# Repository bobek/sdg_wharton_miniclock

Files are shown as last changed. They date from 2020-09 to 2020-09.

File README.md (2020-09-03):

# SDK Electronics Mini Clock

[Wharton Studio Clocks](https://www.wharton.co.uk/digital-clocks/4900050-radio-tv-studio-digital-clocks.htm) are pretty iconic. You can meet their iconic design in many TV and Radio studios around the world (I first met them, when being at CERN). They are a bit pricey.

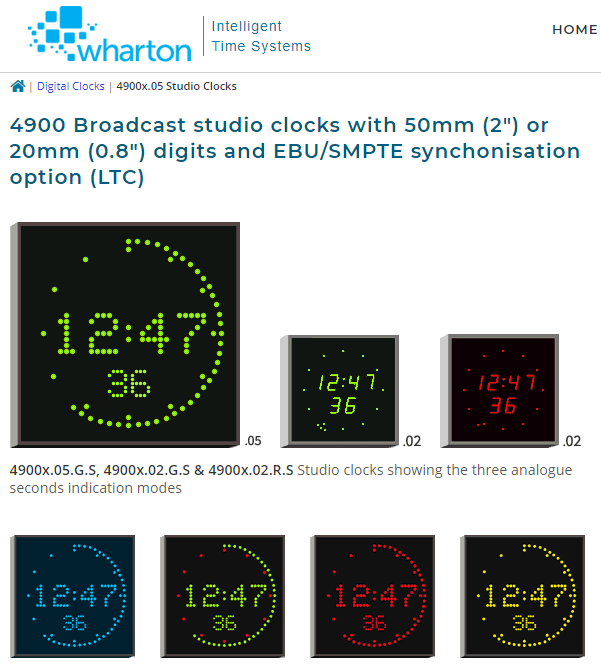
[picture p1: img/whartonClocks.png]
Wharton Studio clocks


Fortunately, Steven from SDG Electronics have designed [mini clock](https://sdgelectronics.co.uk/wharton/) inspired by Wharton's look. Check the project page for an excellent videos describing the whole design as well as walk-through how to upload production files to JLCPCB for manufacturing.

Purpose of this repository is to provide mirror for the production files as well as to have a place to keep history of changes into the firmware. And maybe also to collaborate. PR are welcome.

Project structure:
- [`fw`](fw/): Code for ESP32-WROOM-32D using Espressif IDF.
- [`hw`](hw/): Hardware design files.
- [`hw_prodfiles`](hw_prodfiles/): Hardware production files. Tested with JLCPCB. Layer stack is `GTL--G2L--G3L--GBL`.

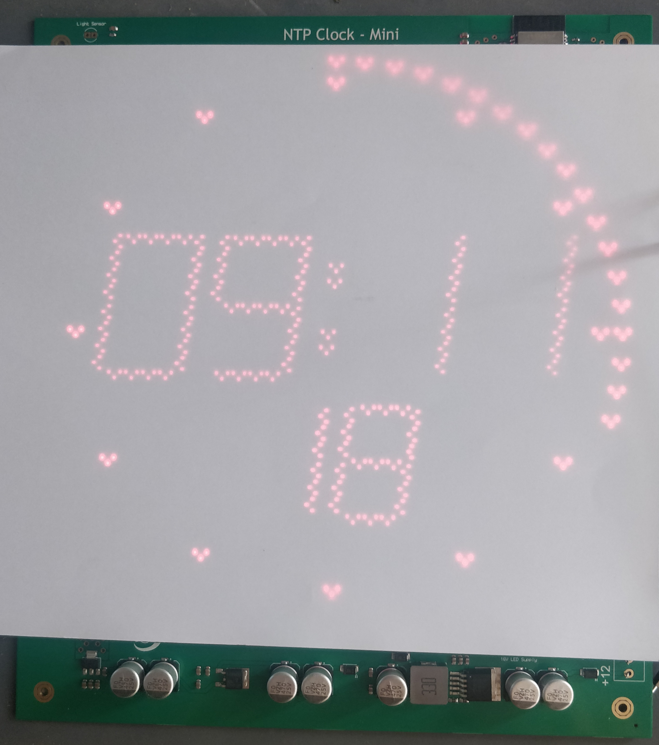
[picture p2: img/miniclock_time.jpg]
Mini Clock showing time

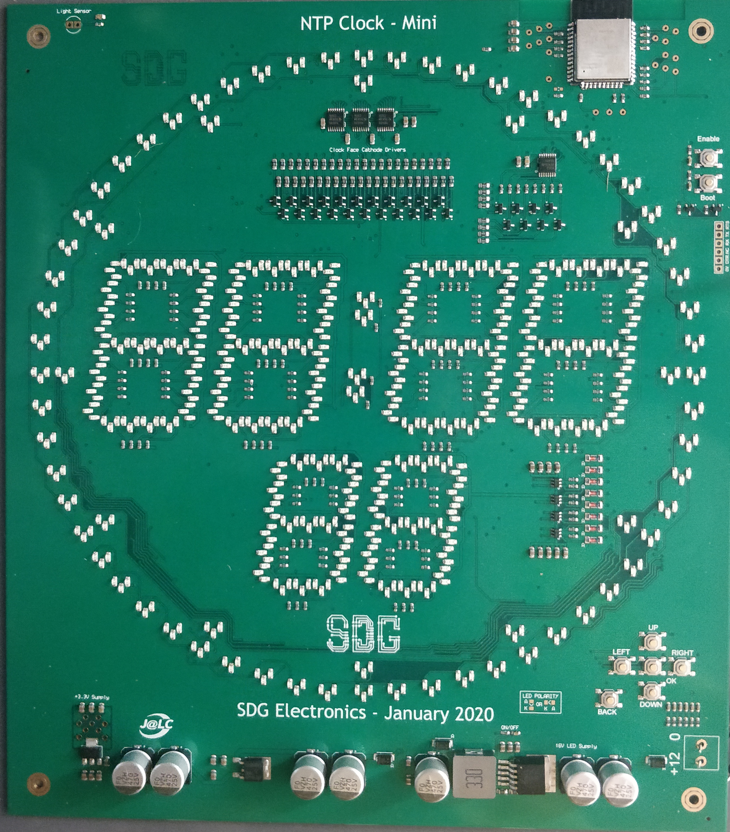
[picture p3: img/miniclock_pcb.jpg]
Mini Clock PCB


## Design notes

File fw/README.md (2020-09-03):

# Mini Clock Firmware

Firmware uses Espressif ESP-IDF. I've initially tried to get it working with PlatformIO, but was not successful as there are compatibility issues between cmake based IDF vs PlatformIO. Thus project is using IDF directly. I am on Linux (Debian), so the following steps are tested only there.

- Install IDF to your computer as described at [Espressif documentation](https://docs.espressif.com/projects/esp-idf/en/latest/esp32/get-started/index.html).
- [Configure your environment](https://docs.espressif.com/projects/esp-idf/en/latest/esp32/get-started/index.html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). For example by `source ~/esp/esp-idf/export.sh`.
- Configure project with `idf.py menuconfig`. There is also a configuration section `Small Clock Configuration`.
- Build with `idf.py build` and flash with `idf.py flash`.

## Configuring local timezone

There is a `LOCAL_TZ_DATA` configuration option. It expects tzdata timezone configuration string. If on Linux, you can use the simple python script `get_tz_data.py` to get it from your local tzdata definition (typically located at `/usr/share/zoneinfo/`). For example:

```
$ ./get_tz_data.py Europe/Prague
CET-1CEST,M3.5.0,M10.5.0/3
$ ./get_tz_data.py America/New_York       
EST5EDT,M3.2.0,M11.1.0
```

You can get list of possible timezone names with `timedatectl list-timezones` or just simply check which files are in the zoneinfo directory.

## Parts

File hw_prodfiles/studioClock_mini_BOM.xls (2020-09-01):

Comment | Designator | Footprint | LCSC Part #
2.2uF | C4 C5 C18 C19 C72 | 0805 | C15850
10uF | C6-9 C20 C21 C25-30 C32 C34 C36 C38 C75 C76 C78 C79 C81-87 | 0805 | C15850
100nF | C10-17 C80 | 0603 | C14663
470uF 25V | C23 C24 C68 C70 C73 C74 C77 | ELECT-10X10 | C266042
100nF | C31 C33 C35 C37 C67 | 0805 | C49678
SS54 | D2 D171 D172 | DO-214AC | C22452
LED | D3-170 D183-500 D501-704 | 0805LED | C72037
33uH | L2 | 12.5X2.5 IND | C149576
S8050 | Q1-2 Q7-36 | SOT23-3 | C2146
WST2011 | Q3-6 | SOT23-6 | C148368
10k | R1-3 R8-14 R446-447 | 0603 | C25804
1R | R4-7 R71-74 R429-430 R432 R433 R435 R436 R438 R444 R445 | 0603 | C22936
10R | R15-70 R75-176 | 0603 | C22859
1k | R177-183 R236 R451 | 0603 | C21190
2k | R184-191 | 0603 | C22975
1k | R192-199 R208-215 R224-229 | 0805 | C17513
51R | R200-207 R216-223 R230-235 | 0805 | C17738
2k | R452 | 0805 | C17604
22k | R453 | 0805 | C17560
470R | R454-461 | 0805 | C17710
AMS1117-3.3 | RG2 | SOT223-3 | C6186
XL6019 | RG3 | TO-263-5E | C73018
TACTILE5X5 | SW1-8 | TS-1187A | C318889
L7805 | U1 | TO252 | C310413
SN74AHC595PWR | U6-9 | TSSOP16 | C271269
ZMM5V6 | ZD1-8 | MINIMELF | C8062

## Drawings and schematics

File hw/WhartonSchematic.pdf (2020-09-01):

A | B | C | D | E | F | G | H | J | K

0

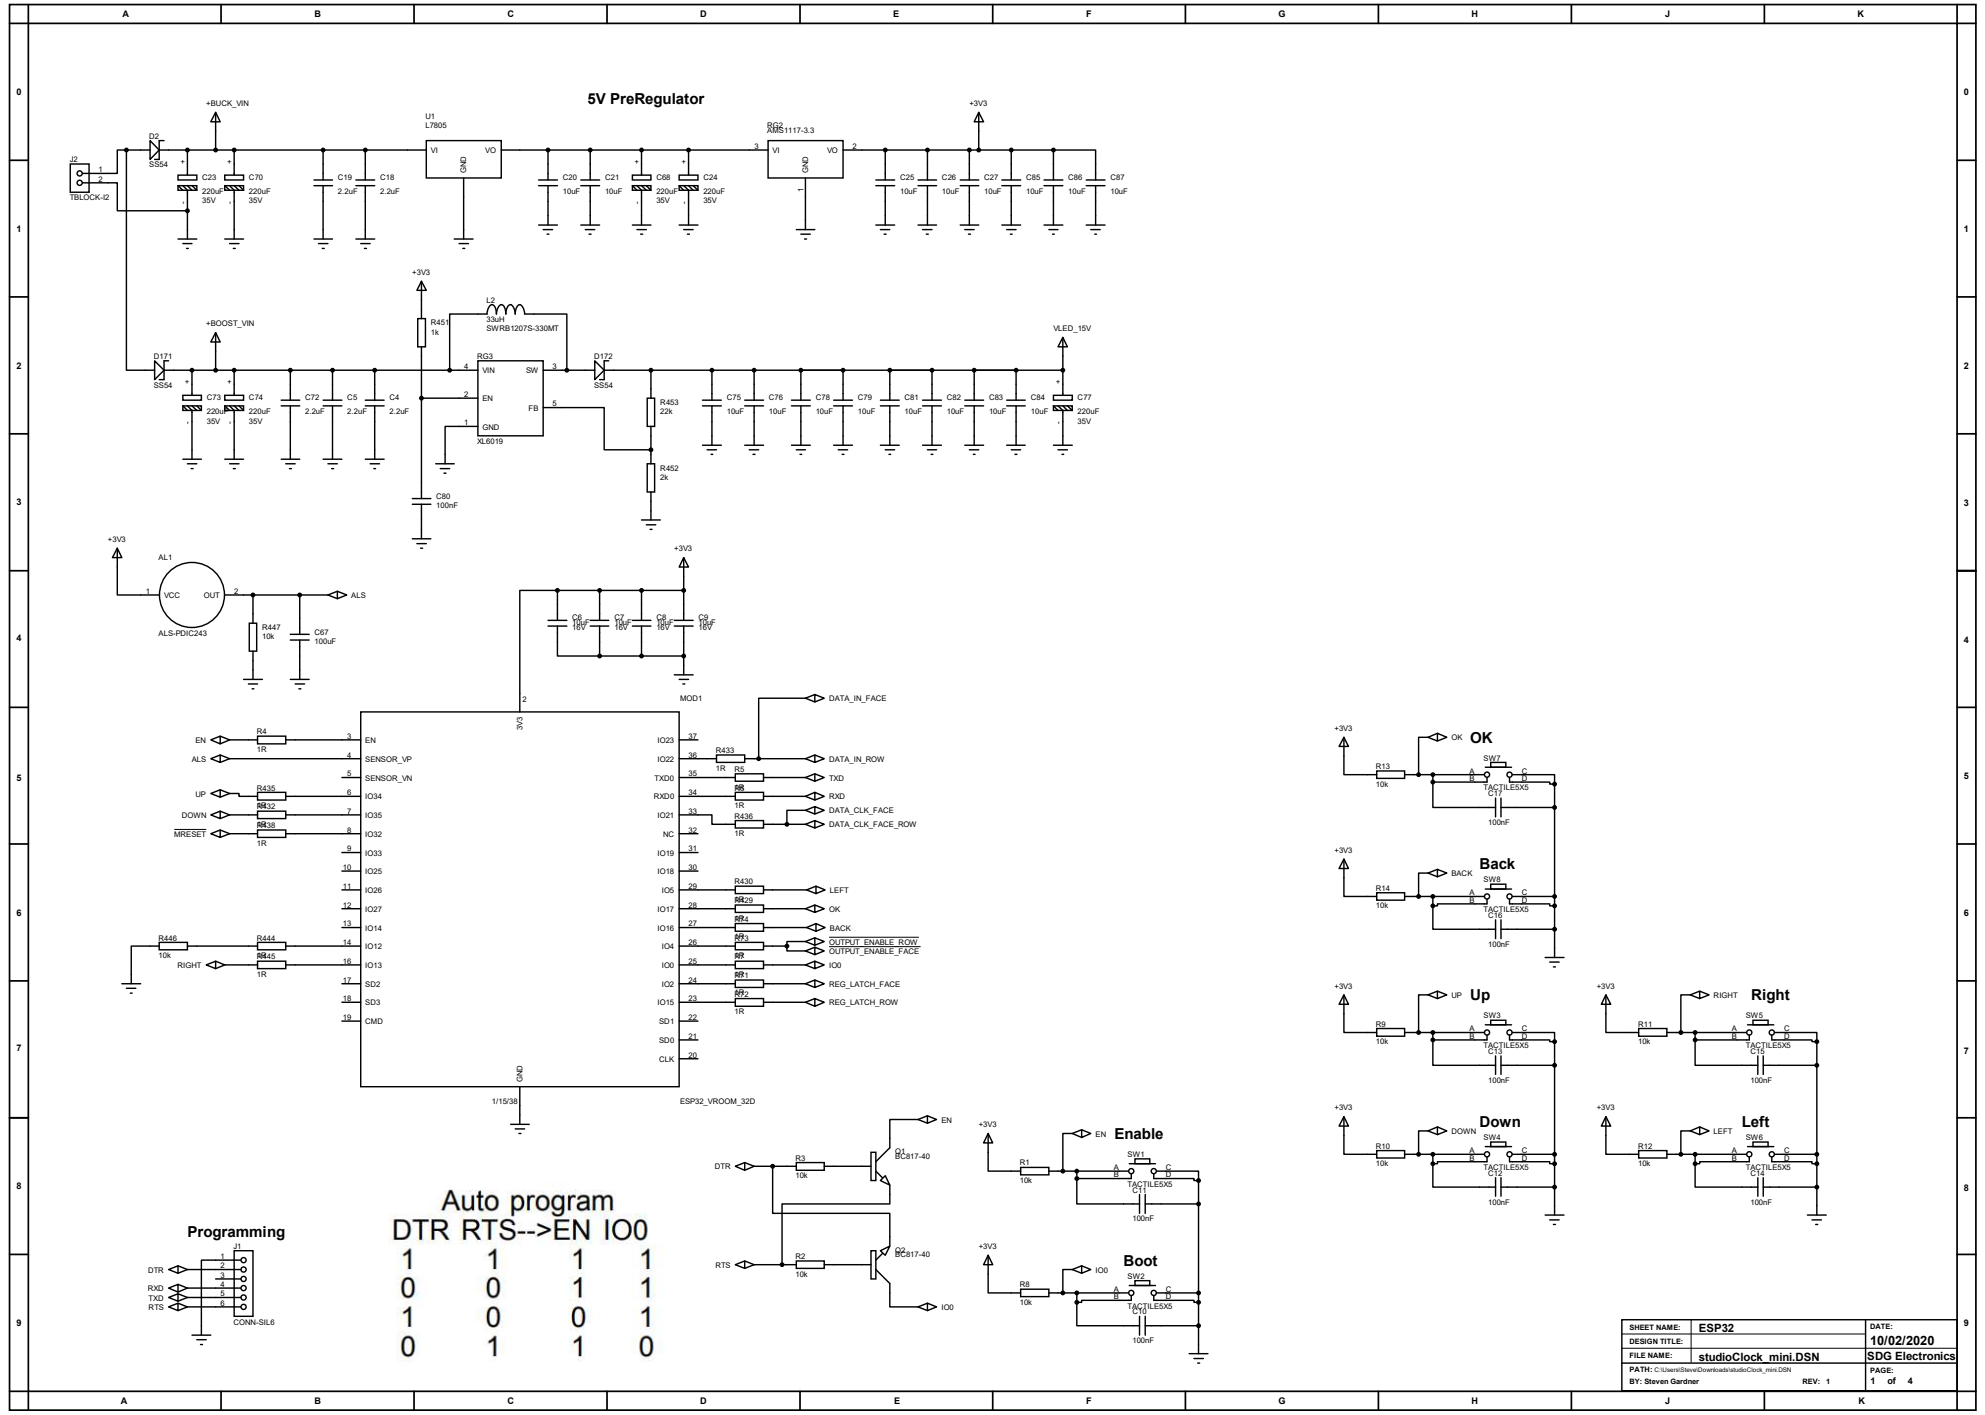
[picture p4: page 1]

PATH: C:\Users\Steve\Downloads\studioClock_mini.DSN

### LED A K

### LED A K

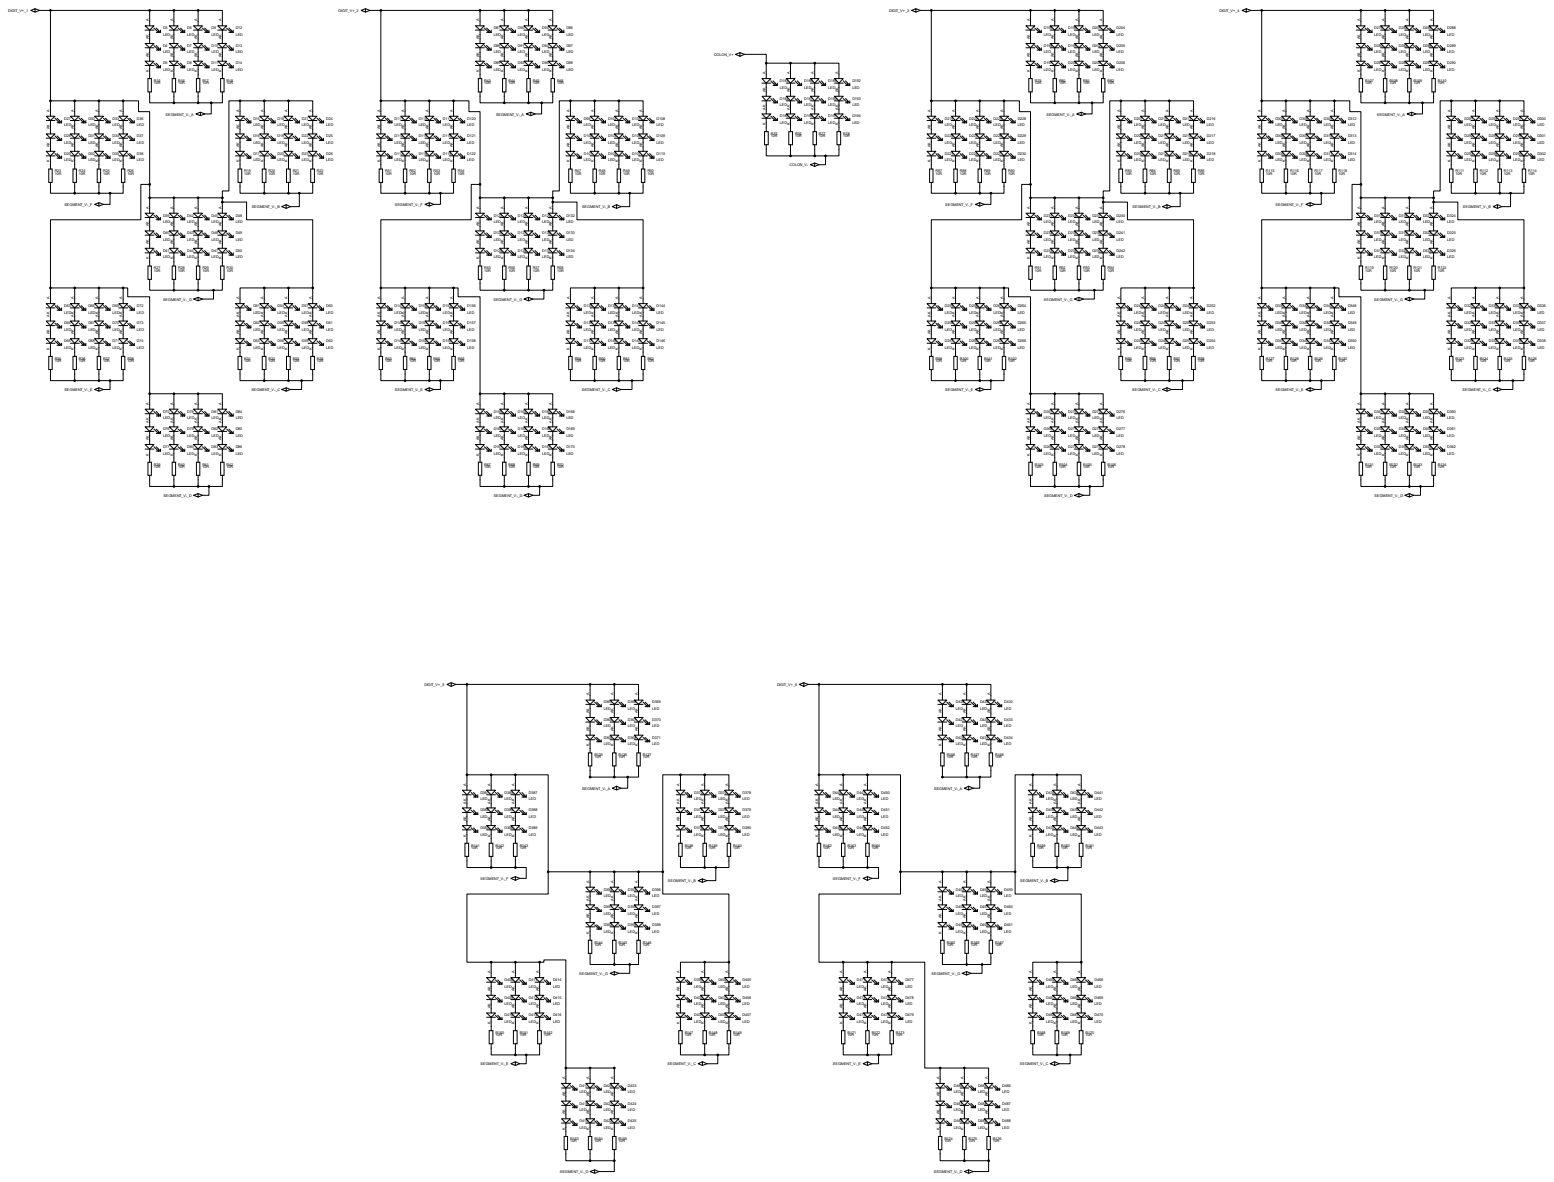
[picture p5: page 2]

1

1

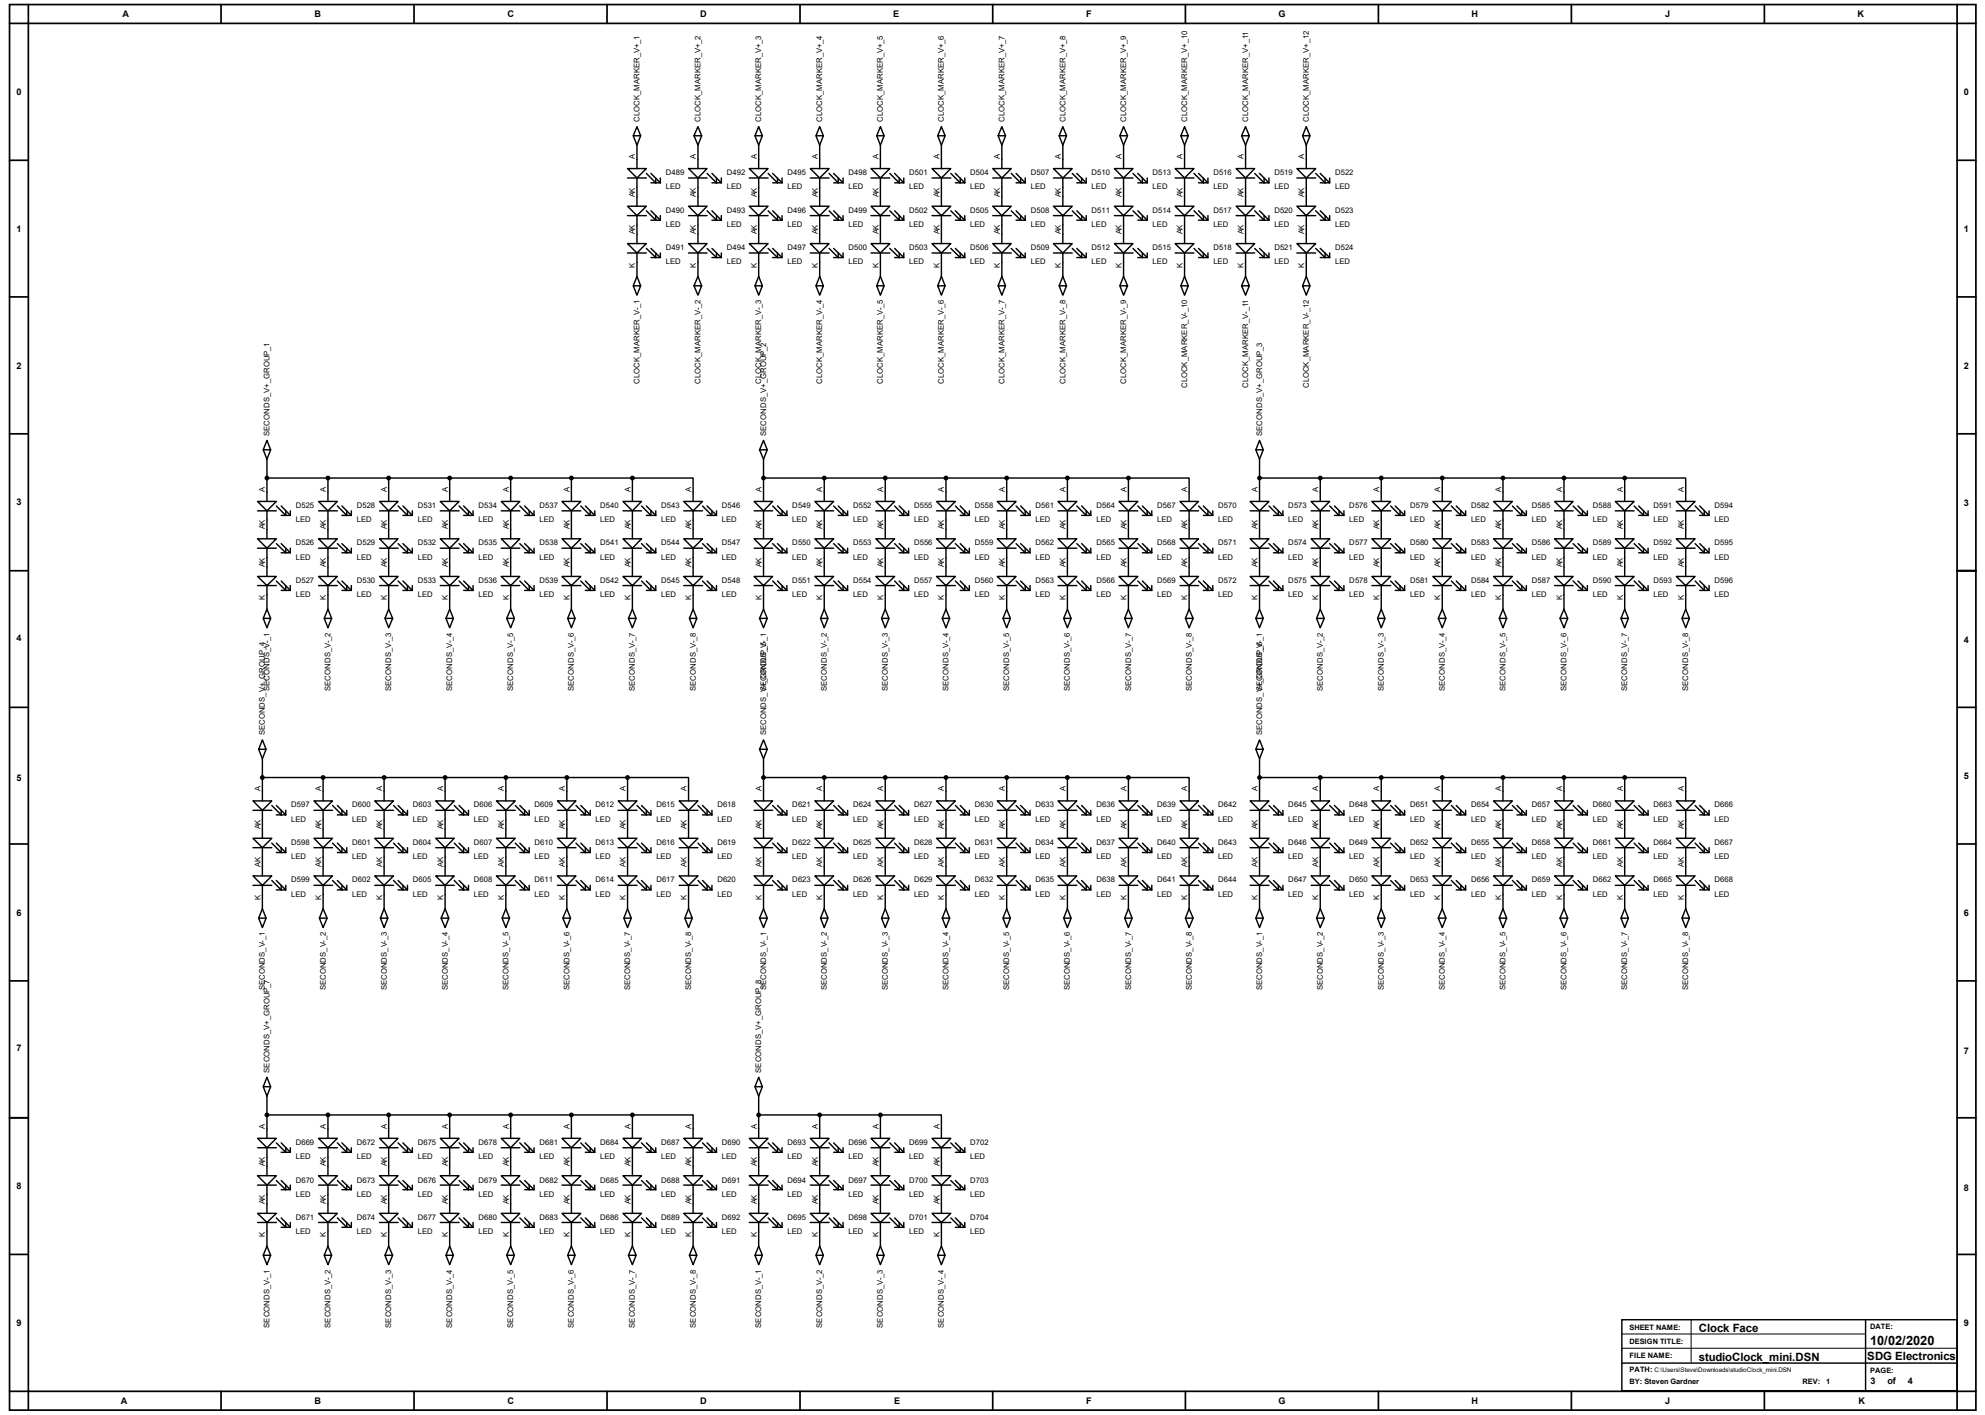
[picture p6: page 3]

1

1

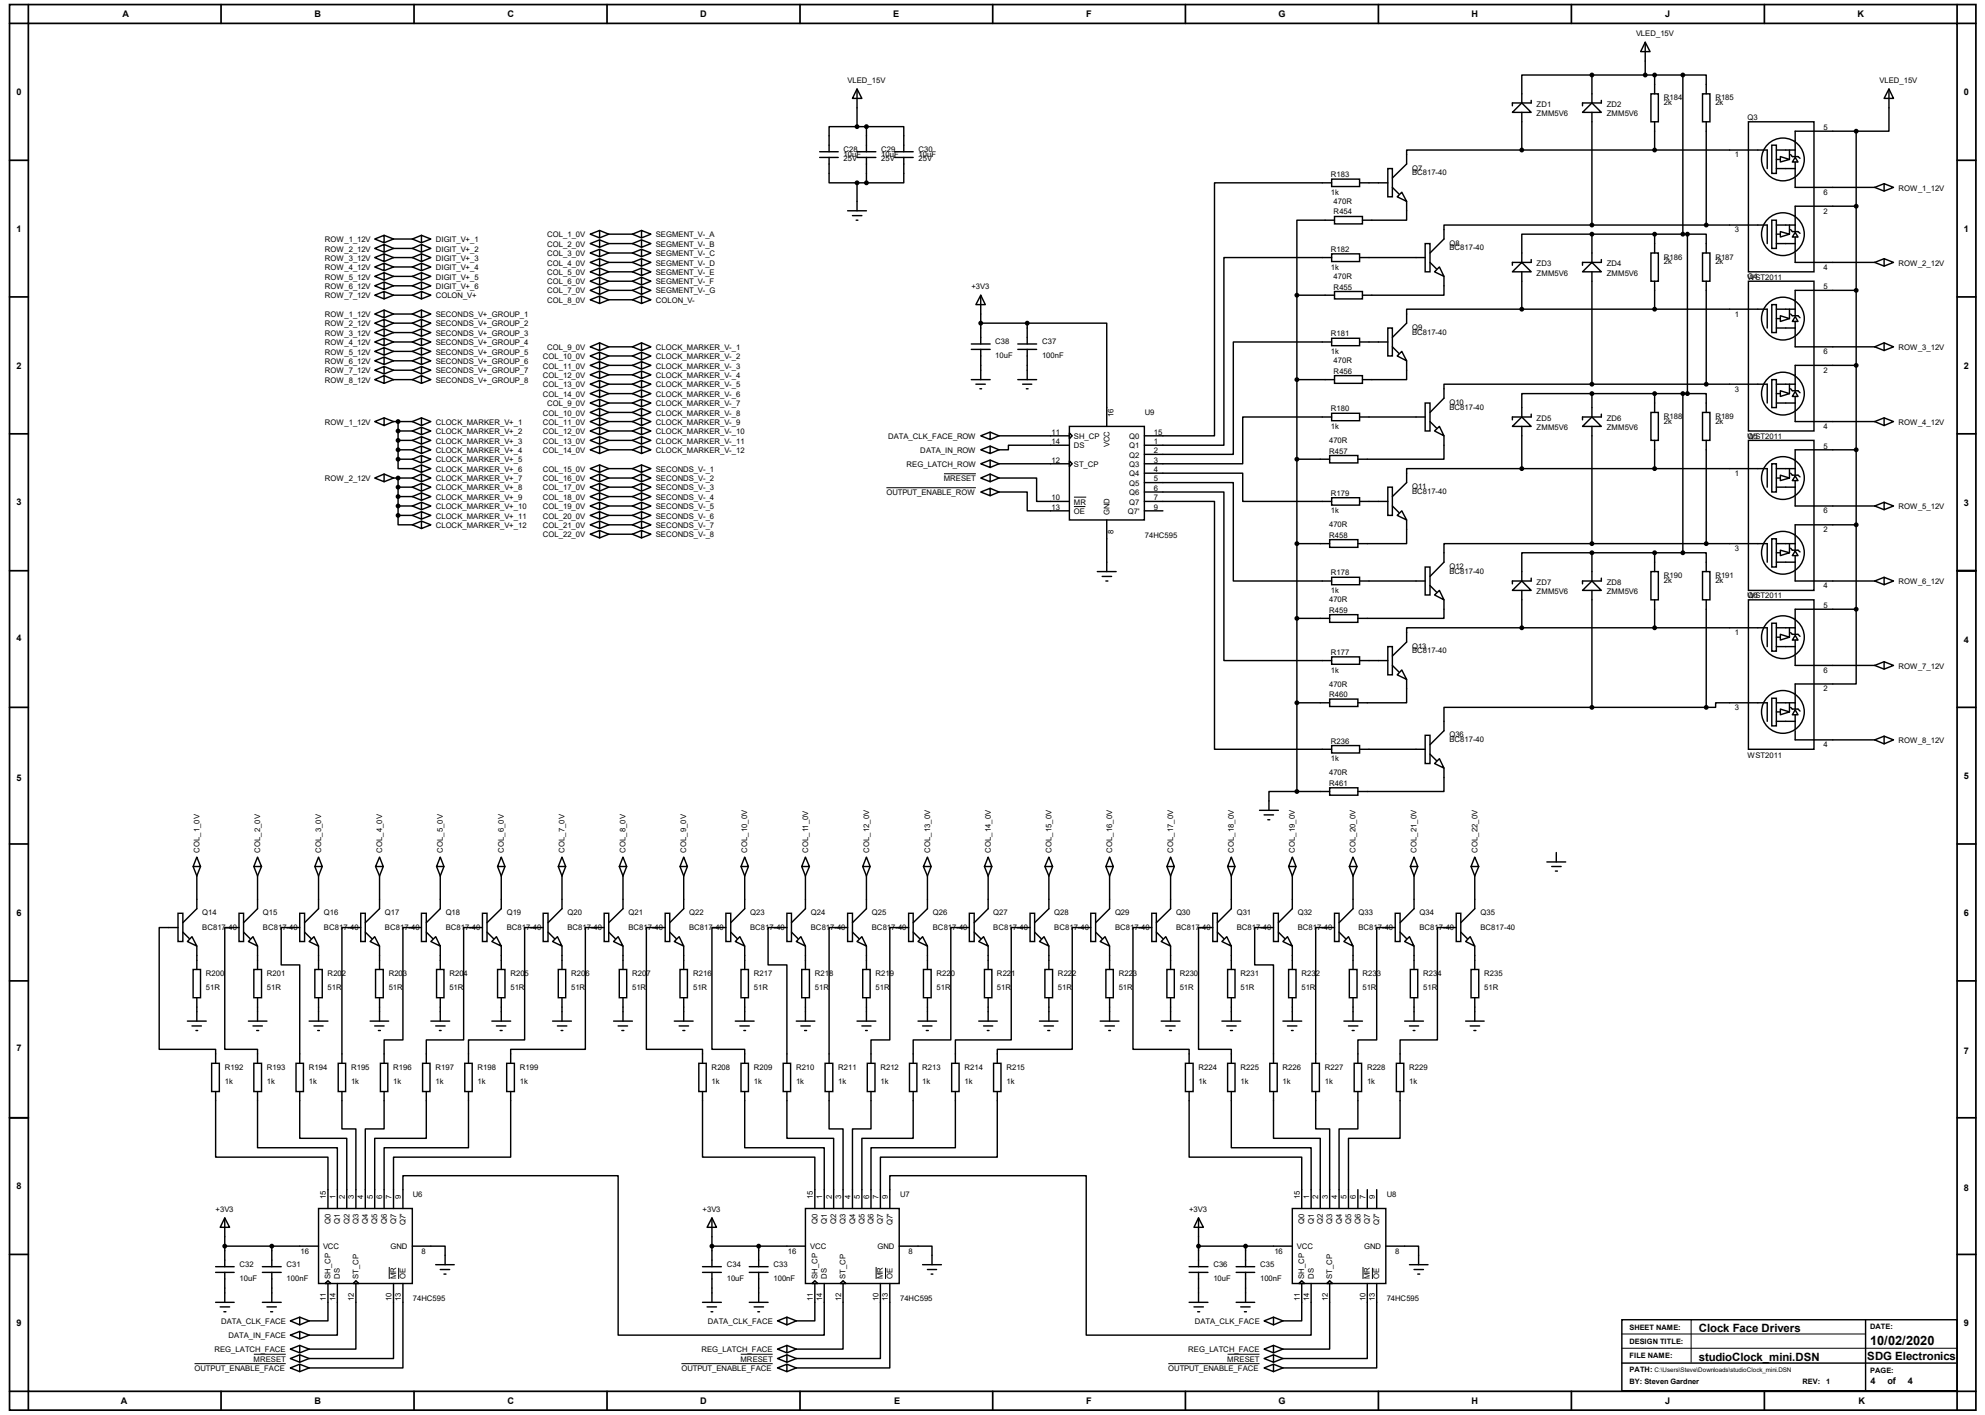
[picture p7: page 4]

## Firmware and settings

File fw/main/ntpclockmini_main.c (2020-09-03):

//----------------------------------------------------------------------------------
//	Filename:         ntpclockmini_main.c
//  File Description: Mini Wharton Clock Firmware
//  Processor:        ESP32-WROOM-32
//
//  Name:             Steven Gardner
//  Company:          SDG Electronics
//  Creation Date:    1st April 2020
//
//  Notes:
//
//----------------------------------------------------------------------------------
#include <string.h>
#include <time.h>
#include <sys/time.h>
#include "freertos/FreeRTOS.h"
#include "freertos/task.h"
#include "freertos/event_groups.h"
#include "esp_system.h"
#include "esp_event.h"
#include "esp_log.h"
#include "esp_attr.h"
#include "esp_sleep.h"
#include "nvs_flash.h"
#include "esp_sntp.h"
#include "esp_timer.h"
#include "esp_wifi.h"
#include "driver/timer.h"
#include "driver/spi_master.h"
#include "driver/gpio.h"
#include "driver/ledc.h"
#include "brightnessControl.h"
#include <cJSON.h>

static const char *TAG = "Mini Wharton Clock";

// Helpful time related macros
#define SECONDS(X) ((X) * (1000 / portTICK_RATE_MS))
#define MINUTES(Y) SECONDS(60 * (Y) )

RTC_DATA_ATTR static int boot_count = 0;

#define DATA_CLK			21
#define DATA_BITS   		22
#define OUTPUT_ENABLE_INV	4
#define LATCH_CATHODES		2
#define LATCH_ANODES		15
#define MRESET_INV			32

#define TESTPIN				23

// SPI Pin Config
#define PIN_NUM_MISO -1
#define PIN_NUM_MOSI 22
#define PIN_NUM_CLK  21
#define PIN_NUM_CS   -1



/** PIN CONFIGURATION
 * Firstly the shift registers
 * IO23 = DATA CLOCK
 * IO22 = DATA BITSTREAM
 * IO4  = _OUTPUT ENABLE
 * IO2  = LATCH FACE (CATHODES)
 * IO15 = LATCH ROW (ANODES)
 * IO32 = _MRESET
 *
 * Then the buttons
 * IO34 = UP
 * IO35 = DOWN
 * IO18 = RIGHT
 * IO5  = LEFT
 * IO17 = OK
 * IO16 = BACK
 *
 * Analogue Inputs
 * SENSOR_VP = Ambient Light Sensor
**/
#define OPT_TENS 2
#define OPT_ONES 1
#define OPT_BOTH 0

#define REFRESH_COMPLETE 0
#define REFRESH_ANODES   1
#define REFRESH_CATHODES 2
#define REFRESH_DISABLE_ANODES 3

const uint8_t segmentMap[] = {
// XGFEDCBA
 0b00111111, // 0
 0b00000110, // 1
 0b01011011, // 2
 0b01001111, // 3
 0b01100110, // 4
 0b01101101, // 5
 0b01111101, // 6
 0b00000111, // 7
 0b01111111, // 8
 0b01101111, // 9
 0b01110111, // A
 0b01111100, // B
 0b00111001, // C
 0b01011110, // D
 0b01111001, // E
 0b01110001  // F
};

const char dowNames[7][10] = {"Sun", "Mon", "Tue", "Wed", "Thu", "Fri", "Sat"};
const char monthNames[12][10] = {"January", "February", "March", "April", "May", "June", "July", "August", "September", "October", "November", "December"};
const char dateEnds[31][3] = {"st", "nd", "rd", "th", "th", "th", "th", "th", "th", "th", "th", "th", "th", "th", "th", "th", "th", "th", "th", "th", "st", "nd", "rd", "th", "th", "th", "th", "th", "th", "th", "st"};


// Wifi settings will be taken from "menucofing"
#define WIFI_SSID           CONFIG_ESP_WIFI_SSID
#define WIFI_PASS           CONFIG_ESP_WIFI_PASSWORD
#define WIFI_MAXIMUM_RETRY  CONFIG_ESP_MAXIMUM_RETRY
#define SNTP_SERVER_NAME    CONFIG_SNTP_SERVER_NAME
#define LOCAL_TZ_DATA       CONFIG_LOCAL_TZ_DATA

static int s_wifi_retry_num = 0;

/* FreeRTOS event group to signal when we are connected*/
static EventGroupHandle_t s_wifi_event_group;

/* The event group allows multiple bits for each event, but we only care about two events:
 * - we are connected to the AP with an IP
 * - we failed to connect after the maximum amount of retries */
#define WIFI_CONNECTED_BIT BIT0
#define WIFI_FAIL_BIT      BIT1

/**             23 22 21 20 19 18 17 16   15 14 13 12 11 10   9  8  7  6  5  4  3  2    1  0
               [0  1  2  3  4  5  6  7    8  9  10 11 12 13   14 15 16 17 18 19 20 21   22 23]
        S      |-     SEGMENTS      -|   |-  MARKERS   -|    |-    SECONDS        -|   NC NC
HOURS,T 0  1    A  B  C  D  E  F  G       1  2  3  4  5  6    0  1  2  3  4  5  6  7
HOURS,O 1  2    A  B  C  D  E  F  G       7  8  9  10 11 12   8  9  10 11 12 13 14 15
MINS,T  2  3    A  B  C  D  E  F  G                           16 17 18 19 20 21 22 23
MINS,O  3  4    A  B  C  D  E  F  G                           24 25 26 27 28 29 30 31
SECS,T  4  5    A  B  C  D  E  F  G                           32 33 34 35 36 37 38 39
SECS,O  5  6    A  B  C  D  E  F  G                           40 41 42 43 44 45 46 47
COLON   6  7                        COL                       48 49 50 51 52 53 54 55
        7  8                                                  56 57 58 59


**/

//-----------------------------------------------------------------------------
// Global Variables
//-----------------------------------------------------------------------------
time_t now = 0;
struct tm timeinfo = { 0 };
uint32_t seconds_bitmap = 0;  // used to temporarily store the seconds bitmap
uint32_t bitstream_face = 0;  // this is the data to be shifted out
uint16_t multiplex_state = 0; // state 0 to 7 for 1/8 multiplexing
uint8_t  time_to_multiplex_anodes = 0;
uint8_t  time_to_multiplex_cathodes = 0;
uint8_t  time_update = 0;
uint8_t	 multiplex_anodeORcathode = REFRESH_DISABLE_ANODES;
uint32_t twentyfourbits = 0;
uint32_t eightbits = 0;
uint32_t eightzeroes = 0;
spi_transaction_t t;

uint8_t g_last = 0;



uint16_t task_core = 0;
//-----------------------------------------------------------------------------
// Function Prototypes
//-----------------------------------------------------------------------------
void create_timer_task_core1(void *param);
void obtain_time(void);
void initialise_sntp(void);
void initialise_wifi(void);
void wifi_init_sta(void);
void app_init(void);
void init_timer(int timer_period_us);
void timer_isr(void* arg);
void multiplex_timer_callback(void* arg);
void onesec_timer_callback(void* arg);

uint16_t display_multiplex_prepare_8bits_anodes(uint16_t multiplex_no);
uint32_t display_multiplex_prepare_24bits(uint16_t multiplex_no);
uint32_t calculate_seconds_bitmap(uint16_t multiplex_stage, uint16_t seconds);
uint16_t decimalToBCD(uint16_t decimal, uint16_t ones_tens);

void spi_pre_transfer_callback(spi_transaction_t *t);
void spi_post_transfer_callback(spi_transaction_t *t);

//-----------------------------------------------------------------------------
// Structs
//-----------------------------------------------------------------------------
time_t now;
struct tm timeinfo;



spi_device_handle_t spi;
spi_bus_config_t buscfg={
    .miso_io_num=PIN_NUM_MISO,
    .mosi_io_num=PIN_NUM_MOSI,
    .sclk_io_num=PIN_NUM_CLK,
    .quadwp_io_num=-1,
    .quadhd_io_num=-1,
    .max_transfer_sz=24
};

spi_device_interface_config_t devcfg={
	.command_bits		= 0,
	.dummy_bits			= 0,
	.mode				= 0,                //SPI mode 0
	.duty_cycle_pos		= 0,
	.cs_ena_posttrans 	= 0,
	.cs_ena_pretrans	= 0,
	.clock_speed_hz		= 5000000,               //Clock out at 5 MHz
	.spics_io_num		= PIN_NUM_CS,       //CS pin
	.flags				= 0,
	.queue_size			= 1,                    //We want to be able to queue 1 transactions at a time
	.pre_cb             = spi_pre_transfer_callback,
	.post_cb			= spi_post_transfer_callback,
};

static intr_handle_t s_timer_handle;
//-----------------------------------------------------------------------------
#ifdef CONFIG_SNTP_TIME_SYNC_METHOD_CUSTOM
void sntp_sync_time(struct timeval *tv)
{
   settimeofday(tv, NULL);
   ESP_LOGI(TAG, "Time is synchronized from custom code");
   sntp_set_sync_status(SNTP_SYNC_STATUS_COMPLETED);
}
#endif

void time_sync_notification_cb(struct timeval *tv)
{
    ESP_LOGI(TAG, "Notification of a time synchronization event");
}

//-------------------------------------------------------------------------
//  NAME
//      create_timer_task_core1
//
//  DESCRIPTION
//!     Display Refresh Timer Task, running on Core 1
//
//  RETURNS
//! @return void
//
//-------------------------------------------------------------------------
void create_timer_task_core1(void *param)
{
    while(1)
     {
        init_timer(500);		// Try setting timer to 1000=1000Hz
        ESP_LOGI(TAG, "Creating Timer ISR:%d\r\n",xPortGetCoreID());
        vTaskDelete( NULL );
    }
}

//-------------------------------------------------------------------------
//  NAME
//      app_main
//
//  DESCRIPTION
//!     Main Loop
//
//  RETURNS
//! @return void
//
//-------------------------------------------------------------------------
void app_main()
{
    ++boot_count;
    ESP_LOGI(TAG, "app_main() is starting...");
    ESP_LOGI(TAG, "Boot count: %d", boot_count);

	app_init();

	ESP_LOGI(TAG, "Initialisation Complete");

	spi_bus_initialize(HSPI_HOST, &buscfg, 0);			// Initialize the SPI bus
	spi_bus_add_device(HSPI_HOST, &devcfg, &spi);		// Attach the device to the SPI bus

    memset(&t, 0, sizeof(t));       //Zero out the transaction

    ESP_LOGI(TAG, "Checking if Time and Date is set");

    if (timeinfo.tm_year < (2016 - 1900)) {
        ESP_LOGI(TAG, "Time is not set yet. Connecting to WiFi and getting time over NTP.");
        obtain_time();
        time(&now);
    }

    char strftime_buf[64];

    ESP_LOGI(TAG, "Setting Time Zone to %s", LOCAL_TZ_DATA);

    // Set timezone to GMT and print local time
    setenv("TZ", LOCAL_TZ_DATA, 1);
    tzset();
    localtime_r(&now, &timeinfo);
    strftime(strftime_buf, sizeof(strftime_buf), "%c", &timeinfo);
    ESP_LOGI(TAG, "The current local date/time: %s", strftime_buf);

    ESP_LOGI(TAG, "Creating Timer Task for Multiplexing");
    xTaskCreatePinnedToCore(create_timer_task_core1, "TimerTask", 8192, NULL, 2, NULL, 1);
    ESP_LOGI(TAG, "Creating Brightness Adjustment Task");
    xTaskCreate(brightness_task, "BrightnessTask", 8192, NULL, 20, NULL);

    ESP_LOGI(TAG, "Starting Main Task...");

	while (1)
	{
		if(time_update == 1)
		{
			time_update = 0;
			time(&now);
			localtime_r(&now, &timeinfo);
		}
		vTaskDelay(250 / portTICK_PERIOD_MS);
	}


}

void obtain_time(void)
{
    // wait for time to be set

    int retry = 0;
    const int retry_count = 30;
    while (sntp_get_sync_status() == SNTP_SYNC_STATUS_RESET && ++retry < retry_count+1) {
        ESP_LOGI(TAG, "Waiting for system time to be set... (%d/%d)", retry, retry_count);
        vTaskDelay(2000 / portTICK_PERIOD_MS);
    }
    time(&now);
    localtime_r(&now, &timeinfo);
    // Note - time will be checked over WiFi every 10 minutes (600000ms) as set in SDK Config -> LWIP -> SNTP
}

void initialise_sntp(void)
{
    ESP_LOGI(TAG, "Initializing SNTP (%s)", SNTP_SERVER_NAME);
    sntp_setoperatingmode(SNTP_OPMODE_POLL);
    sntp_setservername(0, SNTP_SERVER_NAME);
    sntp_set_time_sync_notification_cb(time_sync_notification_cb);
    sntp_set_sync_mode(SNTP_SYNC_MODE_SMOOTH);
    sntp_init();
}

void initialise_wifi(void)
{
    // initialize NVS flash, needed for WI-FI usage
    esp_err_t ret = nvs_flash_init();
    if (ret == ESP_ERR_NVS_NO_FREE_PAGES || ret == ESP_ERR_NVS_NEW_VERSION_FOUND) {
        ESP_ERROR_CHECK(nvs_flash_erase());
        ret = nvs_flash_init();
    }
    ESP_ERROR_CHECK(ret);

    ESP_LOGI(TAG, "ESP_WIFI_MODE_STA");
    wifi_init_sta();
}

//-------------------------------------------------------------------------
//  NAME
//      app_init
//
//  DESCRIPTION
//!     Initialises module
//
//  RETURNS
//! @return void
//
//-------------------------------------------------------------------------
void app_init(void)
{
	//----------------------------------------------------------
	// Configure GPIO
	//----------------------------------------------------------
	gpio_set_direction(LATCH_CATHODES, GPIO_MODE_OUTPUT);
	gpio_set_level(LATCH_CATHODES, 0);
	gpio_pad_select_gpio(LATCH_ANODES);
	gpio_set_direction(LATCH_ANODES, GPIO_MODE_OUTPUT);
	gpio_set_level(LATCH_ANODES, 0);
	gpio_set_direction(MRESET_INV, GPIO_MODE_OUTPUT);
	gpio_set_level(MRESET_INV, 0);
	gpio_set_level(LATCH_CATHODES, 1);
	gpio_set_level(LATCH_ANODES, 1);
	gpio_set_level(MRESET_INV, 1);

	adc_setup();


	//----------------------------------------------------------
	// Configure Timers
	//----------------------------------------------------------
    const esp_timer_create_args_t multiplex_timer_args = {
            .callback = &multiplex_timer_callback,
            /* name is optional, but may help identify the timer when debugging */
            .name = "multiplex"
    };
    esp_timer_handle_t multiplex_timer;
    ESP_ERROR_CHECK(esp_timer_create(&multiplex_timer_args, &multiplex_timer));
    /* The timer has been created but is not running yet */

    const esp_timer_create_args_t onesec_timer_args = {
            .callback = &onesec_timer_callback,
            /* name is optional, but may help identify the timer when debugging */
            .name = "onesec"
    };
    esp_timer_handle_t onesec_timer;
    ESP_ERROR_CHECK(esp_timer_create(&onesec_timer_args, &onesec_timer));

    /* Start the timers */
    // ESP_ERROR_CHECK(esp_timer_start_periodic(multiplex_timer, 1500));	//0.00125s - 800Hz 1250
    ESP_ERROR_CHECK(esp_timer_start_periodic(onesec_timer, 250000));	//1s - 4Hz

	//----------------------------------------------------------
	// Configure PWM
	//----------------------------------------------------------
    initialisebrightnessControlPWM();

 	//----------------------------------------------------------
 	// Configure WiFi and SNTP
 	//----------------------------------------------------------
    initialise_wifi();
    initialise_sntp();
}

//-------------------------------------------------------------------------
//  NAME
//      init_timer
//
//  DESCRIPTION
//!     Initialises Timer 0 from Timer Group 0 with interrupt
//
//  RETURNS
//! @return void
//
//-------------------------------------------------------------------------
void init_timer(int timer_period_us)
{
    timer_config_t config = {
            .alarm_en = true,
            .counter_en = false,
            .intr_type = TIMER_INTR_LEVEL,
            .counter_dir = TIMER_COUNT_UP,
            .auto_reload = true,
            .divider = 80   /* 1 us per tick */
    };

    timer_init(TIMER_GROUP_0, TIMER_0, &config);
    timer_set_counter_value(TIMER_GROUP_0, TIMER_0, 0);
    timer_set_alarm_value(TIMER_GROUP_0, TIMER_0, timer_period_us);
    timer_enable_intr(TIMER_GROUP_0, TIMER_0);
    timer_isr_register(TIMER_GROUP_0, TIMER_0, &timer_isr, NULL, 0, &s_timer_handle);

    timer_start(TIMER_GROUP_0, TIMER_0);
}

//-------------------------------------------------------------------------
//  NAME
//      timer_isr
//
//  DESCRIPTION
//!     The Timer 0 interrupt
//
//  RETURNS
//! @return void
//
//-------------------------------------------------------------------------
void timer_isr(void* arg)
{

    TIMERG0.int_clr_timers.t0 = 1;
    TIMERG0.hw_timer[0].config.alarm_en = 1;

    task_core = xPortGetCoreID();

		twentyfourbits = display_multiplex_prepare_24bits(multiplex_state);
		eightbits = display_multiplex_prepare_8bits_anodes(multiplex_state);

		multiplex_state++;
		if(multiplex_state > 7) multiplex_state = 0;

		gpio_set_level(LATCH_CATHODES, 0);
		gpio_set_level(LATCH_ANODES, 0);
		gpio_set_level(MRESET_INV, 0);
		gpio_set_level(LATCH_CATHODES, 1);
		gpio_set_level(LATCH_ANODES, 1);
		gpio_set_level(MRESET_INV, 1);
		gpio_set_level(LATCH_CATHODES, 0);
		gpio_set_level(LATCH_ANODES, 0);


			if(multiplex_state < 8)
			{
				multiplex_anodeORcathode = REFRESH_CATHODES;
				memset(&t, 0, sizeof(t));       //Zero out the transaction
		    	t.length=24;                     // Command is 24 bits
		    	t.tx_buffer=&twentyfourbits;     // Data in the buffer
		    	spi_device_queue_trans(spi, &t, portMAX_DELAY);
			}

			while(multiplex_anodeORcathode == REFRESH_CATHODES)
			{

			};

			if(multiplex_state < 8)
			{
				multiplex_anodeORcathode = REFRESH_ANODES;
				memset(&t, 0, sizeof(t));       //Zero out the transaction
		    	t.length=8;                     // Command is 8 bits
		    	t.tx_buffer=&eightbits;         // Data in the buffer
		    	spi_device_queue_trans(spi, &t, portMAX_DELAY);
			}

			//resumebrightnessControlPWM();
}

//-------------------------------------------------------------------------
//  NAME
//      multiplex_timer_callback
//
//  DESCRIPTION
//!     Callback from high resolution timer for Multiplexing the display
//
//  RETURNS
//! @return void
//
//-------------------------------------------------------------------------
void multiplex_timer_callback(void* arg)
{
//	time_to_multiplex_cathodes = 1;
//	display_multiplex(multiplex_state++);
//	if(multiplex_state > 10) multiplex_state = 0;
}

//-------------------------------------------------------------------------
//  NAME
//      onesec_timer_callback
//
//  DESCRIPTION
//!     Callback from high resolution timer for updating the time
//
//  RETURNS
//! @return void
//
//-------------------------------------------------------------------------
void onesec_timer_callback(void* arg)
{
	time_update = 1;
}

//-------------------------------------------------------------------------
//  NAME
//      display_multiplex_prepare_8bits_anodes
//
//  DESCRIPTION
//!     Prepares 8 bits of data to the 74HC595 Shift Registers for
//      clock face multiplex rows (1-8)
//
//  RETURNS
//! @return void
//
//-------------------------------------------------------------------------
uint16_t display_multiplex_prepare_8bits_anodes(uint16_t multiplex_no)
{
	uint16_t bitfield_data = 0;

	gpio_set_level(LATCH_ANODES, 0);
    // Data is latched on rising edge of clock
	if(multiplex_no > 7)
	{
		bitfield_data = 0;
	}
	else
	{
		//bitfield_data = 0x0080 >> multiplex_no;   // shifts is a value 0-7 // Normal way for shifting out manually

		bitfield_data = 0x0001 << multiplex_no;   // shifts is a value 0-7	 // Reversed for SPI
	}
    return(bitfield_data);
}

//-------------------------------------------------------------------------
//  NAME
//      display_multiplex_prepare_24bits_reversed
//
//  DESCRIPTION
//!     Call this with valid data in the tm structure to prepare 24 bits for multiplexing
//!     multiplex_no should be 0-7 for the 1 in 8 multiplexing
//
//  RETURNS
//! @return void
//
//-------------------------------------------------------------------------
uint32_t display_multiplex_prepare_24bits_reversed(uint16_t multiplex_no)
{
	uint32_t temp_bitmap = 0;     // used to temporarily store the 7 seg bitmap
    bitstream_face = 0;

	// First, all markers will be lit (bit position 10-15)
	bitstream_face = bitstream_face | 0b1111110000000000;
	// Next illuminate seconds
	seconds_bitmap = calculate_seconds_bitmap(multiplex_no, timeinfo.tm_sec);
	seconds_bitmap = seconds_bitmap << 2;
	seconds_bitmap = seconds_bitmap & 0b1111111100;
	bitstream_face = bitstream_face | seconds_bitmap;

	// Now work out which digits to display
	switch (multiplex_no)
	{
		case 0: // Hours, Tens
		{
			temp_bitmap = (uint32_t)segmentMap[(decimalToBCD(timeinfo.tm_hour, OPT_TENS) & 0x0F)];
			temp_bitmap = temp_bitmap << 17;  // Shift into position to copy into bitstream
			break;
		}
		case 1: // Hours, Ones
		{
			temp_bitmap = (uint32_t)segmentMap[(decimalToBCD(timeinfo.tm_hour, OPT_ONES) & 0x0F)];
			temp_bitmap = temp_bitmap << 17;  // Shift into position to copy into bitstream
			break;
		}
		case 2: // Minutes, Tens
		{
			temp_bitmap = (uint32_t)segmentMap[(decimalToBCD(timeinfo.tm_min, OPT_TENS) & 0x0F)];
			temp_bitmap = temp_bitmap << 17;  // Shift into position to copy into bitstream
			break;
		}
		case 3: // Minutes, Ones
		{
			temp_bitmap = (uint32_t)segmentMap[(decimalToBCD(timeinfo.tm_min, OPT_ONES) & 0x0F)];
			temp_bitmap = temp_bitmap << 17;  // Shift into position to copy into bitstream
			break;
		}
		case 4: // Seconds, Tens
		{
			temp_bitmap = (uint32_t)segmentMap[(decimalToBCD(timeinfo.tm_sec, OPT_TENS) & 0x0F)];
			temp_bitmap = temp_bitmap << 17;  // Shift into position to copy into bitstream
			break;
		}
		case 5: // Seconds, Ones
		{
			temp_bitmap = (uint32_t)segmentMap[(decimalToBCD(timeinfo.tm_sec, OPT_ONES) & 0x0F)];
			temp_bitmap = temp_bitmap << 17;  // Shift into position to copy into bitstream
			break;
		}
		case 6: // Colons
		{
			temp_bitmap = 0b10000000000000000;
			break;
		}
		default:
		{
			temp_bitmap = 0;
			break;
		}
	}

	bitstream_face = bitstream_face | (temp_bitmap & 0b111111110000000000000000);
	return bitstream_face;
}
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

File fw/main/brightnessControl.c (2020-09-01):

/*
 * brightnessControl.c
 *
 *  Created on: 29 Mar 2020
 *      Author: Steve
 */
#include "freertos/FreeRTOS.h"
#include "freertos/task.h"
#include "freertos/event_groups.h"
#include <string.h>
#include "driver/adc.h"
#include "esp_adc_cal.h"
#include "driver/gpio.h"
#include "driver/ledc.h"
#include "brightnessControl.h"
#include "esp_log.h"

static const char *TAG = "Brightness Control";

// ADC Setting
#define DEFAULT_VREF    1100
#define LEDC_HS_TIMER          LEDC_TIMER_0
#define LEDC_HS_MODE           LEDC_HIGH_SPEED_MODE
#define LEDC_HS_CH0_GPIO       (4)
#define LEDC_HS_CH0_CHANNEL    LEDC_CHANNEL_0
#define LEDC_TEST_FADE_TIME    1000
#define LEDC_HS_CH1_GPIO       (33)
#define LEDC_HS_CH1_CHANNEL    LEDC_CHANNEL_1
static const adc_atten_t atten = ADC_ATTEN_DB_11;
static const adc_unit_t unit = ADC_UNIT_1;
static const adc_channel_t channel = ADC_CHANNEL_0;

static void check_efuse(void);
static void print_char_val_type(esp_adc_cal_value_t val_type);

static esp_adc_cal_characteristics_t *adc_chars;

ledc_channel_config_t ledc_channel_face = {
            .channel    = LEDC_HS_CH0_CHANNEL,
            .duty       = 0,
            .gpio_num   = LEDC_HS_CH0_GPIO,
            .speed_mode = LEDC_HS_MODE,
            .hpoint     = 0,
            .timer_sel  = LEDC_HS_TIMER
};

ledc_channel_config_t ledc_channel_matrix = {
            .channel    = LEDC_HS_CH1_CHANNEL,
            .duty       = 0,
            .gpio_num   = LEDC_HS_CH1_GPIO,
            .speed_mode = LEDC_HS_MODE,
            .hpoint     = 0,
            .timer_sel  = LEDC_HS_TIMER
};
/* Configure Timers for the LED Controller (Allows PWM Control of LEDS) */
ledc_timer_config_t ledc_timer = {
   .duty_resolution = LEDC_TIMER_9_BIT, // resolution of PWM duty
   .freq_hz = 100000,                    // frequency of PWM signal
   .speed_mode = LEDC_HS_MODE,           // timer mode
   .timer_num = LEDC_HS_TIMER,            // timer index
   .clk_cfg = LEDC_AUTO_CLK,              // Auto select the source clock
};

//----------------------------------------------------------
// Configure ADC
//----------------------------------------------------------
void adc_setup(void)
{
check_efuse();

	// Now configure ADC 1
	adc1_config_width(ADC_WIDTH_BIT_12);
	adc1_config_channel_atten(channel, atten);

	//Characterize ADC
	adc_chars = calloc(1, sizeof(esp_adc_cal_characteristics_t));
	esp_adc_cal_value_t val_type = esp_adc_cal_characterize(unit, atten, ADC_WIDTH_BIT_12, DEFAULT_VREF, adc_chars);
	print_char_val_type(val_type);
}

//-------------------------------------------------------------------------
//  NAME
//      brightness_task
//
//  DESCRIPTION
//!     Do ADC and update the brightness of the LED Display
//
//  RETURNS
//! @return void
//
//-------------------------------------------------------------------------
void brightness_task( void * pvParameters )
{
	uint32_t adc_reading = 0;
	uint32_t scaled_adc_reading = 0;
	for( ;; )
	{
		adc_reading = adc1_get_raw((adc1_channel_t)channel);
	 	//Convert adc_reading to voltage in mV
	 	//uint32_t voltage = esp_adc_cal_raw_to_voltage(adc_reading, adc_chars);
	 	//ESP_LOGI(TAG, "Raw: %d\tVoltage: %dmV\n", adc_reading, voltage);
	 	//ESP_LOGI(TAG, "ADC%d CH%d Raw: %d\t\n", unit, channel, adc_reading);
	 	// ADC Reading from 0-4096
	 	// Should convert to 511-0
		/*
	 	if(adc_reading < 100)
	 	{
	 		scaled_adc_reading = adc_reading;
	 	}
	 	else if(adc_reading < 1000)
	 	{
	 		scaled_adc_reading = ((adc_reading-100) / 2) + 100; // Max of 550
	 	}
	 	else // if less than 4096
	 	{
	 		scaled_adc_reading =  ((adc_reading-1000) / 8) + 550; // Max of 1010
	 	}
	 	if(scaled_adc_reading > 1010)
	 	{
	 		scaled_adc_reading = 1010;
	 	}
	 	// Now 0-1023
	 	scaled_adc_reading = 1015 - scaled_adc_reading;*/

		if(adc_reading < 10)
		{
			scaled_adc_reading =  511;
		}
		else
		{
			if(adc_reading > 4000)
			{
				adc_reading = 4000;
			}
			adc_reading = adc_reading - 10;
			adc_reading = adc_reading / 12;
			scaled_adc_reading = 511-adc_reading;

		}

	 	ESP_LOGI(TAG, "ADC: %d New duty %d\t\n", adc_reading,scaled_adc_reading);

	 	ledc_set_fade_with_time(ledc_channel_face.speed_mode, ledc_channel_face.channel, scaled_adc_reading, LEDC_TEST_FADE_TIME);
	 	ledc_fade_start(ledc_channel_face.speed_mode, ledc_channel_face.channel, LEDC_FADE_NO_WAIT);

	 	ledc_set_fade_with_time(ledc_channel_matrix.speed_mode, ledc_channel_matrix.channel, scaled_adc_reading, LEDC_TEST_FADE_TIME);
	 	ledc_fade_start(ledc_channel_matrix.speed_mode, ledc_channel_matrix.channel, LEDC_FADE_NO_WAIT);
	 	vTaskDelay(1000 / portTICK_PERIOD_MS);
	}
}

//-------------------------------------------------------------------------
//  NAME
//      initialisebrightnessControlPWM
//
//  DESCRIPTION
//!     Set up ledc for PWM operation
//
//  RETURNS
//! @return void
//
//-------------------------------------------------------------------------
void initialisebrightnessControlPWM(void)
{
// Initialize fade service.
    ledc_fade_func_install(0);


 // Set configuration of timer0 for high speed channels
 	 ESP_ERROR_CHECK( ledc_timer_config(&ledc_timer));
 	 ESP_ERROR_CHECK( ledc_channel_config(&ledc_channel_face));
 	 ESP_ERROR_CHECK( ledc_channel_config(&ledc_channel_matrix));

 	 ESP_ERROR_CHECK( ledc_set_duty(ledc_channel_face.speed_mode, ledc_channel_face.channel,  511));
 	 ESP_ERROR_CHECK( ledc_update_duty(ledc_channel_face.speed_mode, ledc_channel_face.channel));
 	 ESP_ERROR_CHECK( ledc_set_duty(ledc_channel_matrix.speed_mode, ledc_channel_matrix.channel,  511));
 	 ESP_ERROR_CHECK( ledc_update_duty(ledc_channel_matrix.speed_mode, ledc_channel_matrix.channel));
}

//-------------------------------------------------------------------------
//  NAME
//      pausebrightnessControlPWM
//
//  DESCRIPTION
//!     Reset timers
//
//  RETURNS
//! @return void
//
//-------------------------------------------------------------------------
void pausebrightnessControlPWM(void)
{
	ledc_timer_pause(ledc_channel_matrix.speed_mode, ledc_channel_face.channel);
}

//-------------------------------------------------------------------------
//  NAME
//      resumebrightnessControlPWM
//
//  DESCRIPTION
//!     Reset timers
//
//  RETURNS
//! @return void
//
//-------------------------------------------------------------------------
void resumebrightnessControlPWM(void)
{
	ledc_timer_resume(ledc_channel_matrix.speed_mode, ledc_channel_face.channel);
}
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

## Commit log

2020-09-01 Original production files
    [studioClock_mini_BOM.xls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]
2020-09-01 Replace L2 for C127811
    [studioClock_mini_BOM.xls]
2020-09-01 Replace L2 with C149576
    [studioClock_mini_BOM.xls]
2020-09-01 Replace sdkconfig with sdkconfig.defaults
    based on
    https://docs.espressif.com/projects/esp-idf/en/latest/esp32/api-guides/build-system.html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
